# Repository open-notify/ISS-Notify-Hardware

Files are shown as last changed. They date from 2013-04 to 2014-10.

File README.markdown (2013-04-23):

# ISS Notify Hardware

ISS Notify is an open hardware project to make a desktop notification lamp
specifically for overhead passes for the International Space Station for a
users location.

ISS Notify is a simple 2 layer board with an AVR microcontroller with USB
and a set of RGB LEDs LED driver/shift registers. It also has a 
real time clock and a LiPo batter charging circuit.

This repo has all of the design files needed for producing the hardware.

Designed in Eagle version 6.3.

Licensed under the TAPR Open Hardware License (www.tapr.org/OHL). See 
LICENSE.txt for full license information.

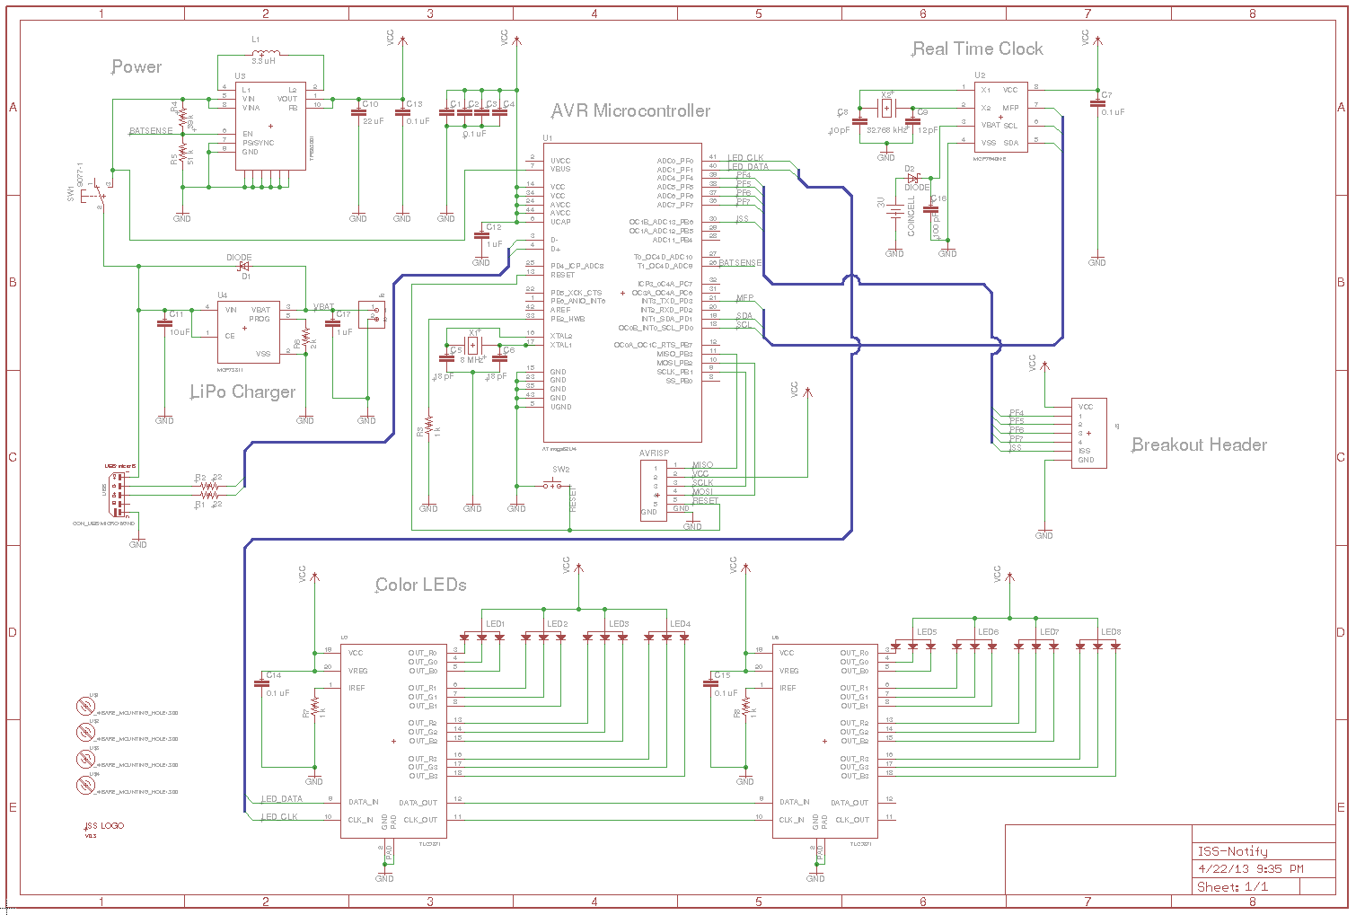
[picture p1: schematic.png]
preview of schematic


 - Download pdf [schematic.pdf](https://github.com/open-notify/ISS-Notify-Hardware/raw/master/schematic.pdf)

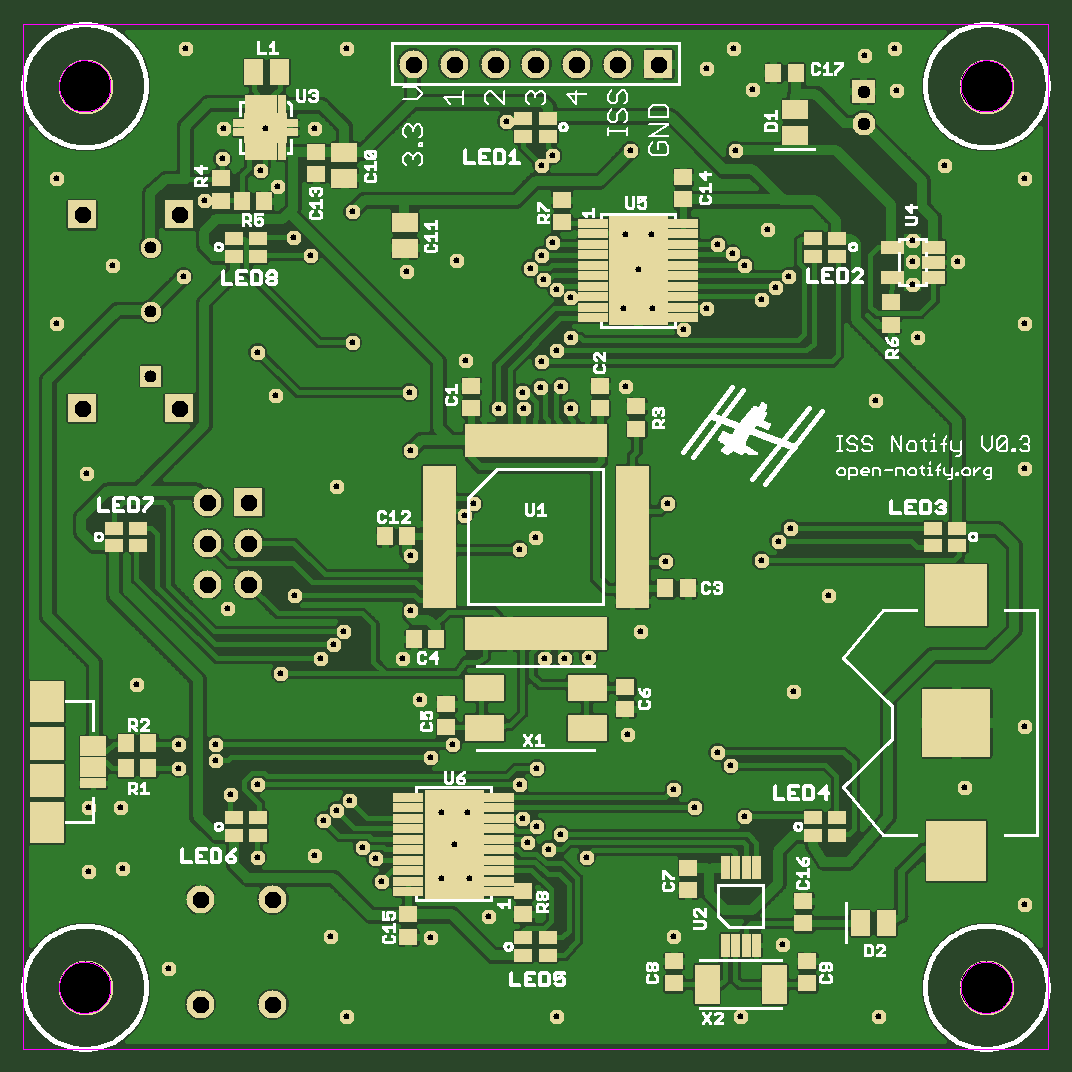
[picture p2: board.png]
preview of board


 - Download pdf [board.pdf](https://github.com/open-notify/ISS-Notify-Hardware/raw/master/board.pdf)

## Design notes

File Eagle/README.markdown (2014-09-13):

# Eagle Files

 - `eagle.epf`: Eagle project
 - `ISS-Notify.lbr`: Eagle parts library
 - `ISS-Notify.sch`: Main board schematic
 - `ISS-Notify.brd`: Main board boardfile
 - `ISS-Notify_Test-Harness.sch`: Test Harness schematic
 - `ISS-Notify_Test-Harness.brd`: Test Harness board

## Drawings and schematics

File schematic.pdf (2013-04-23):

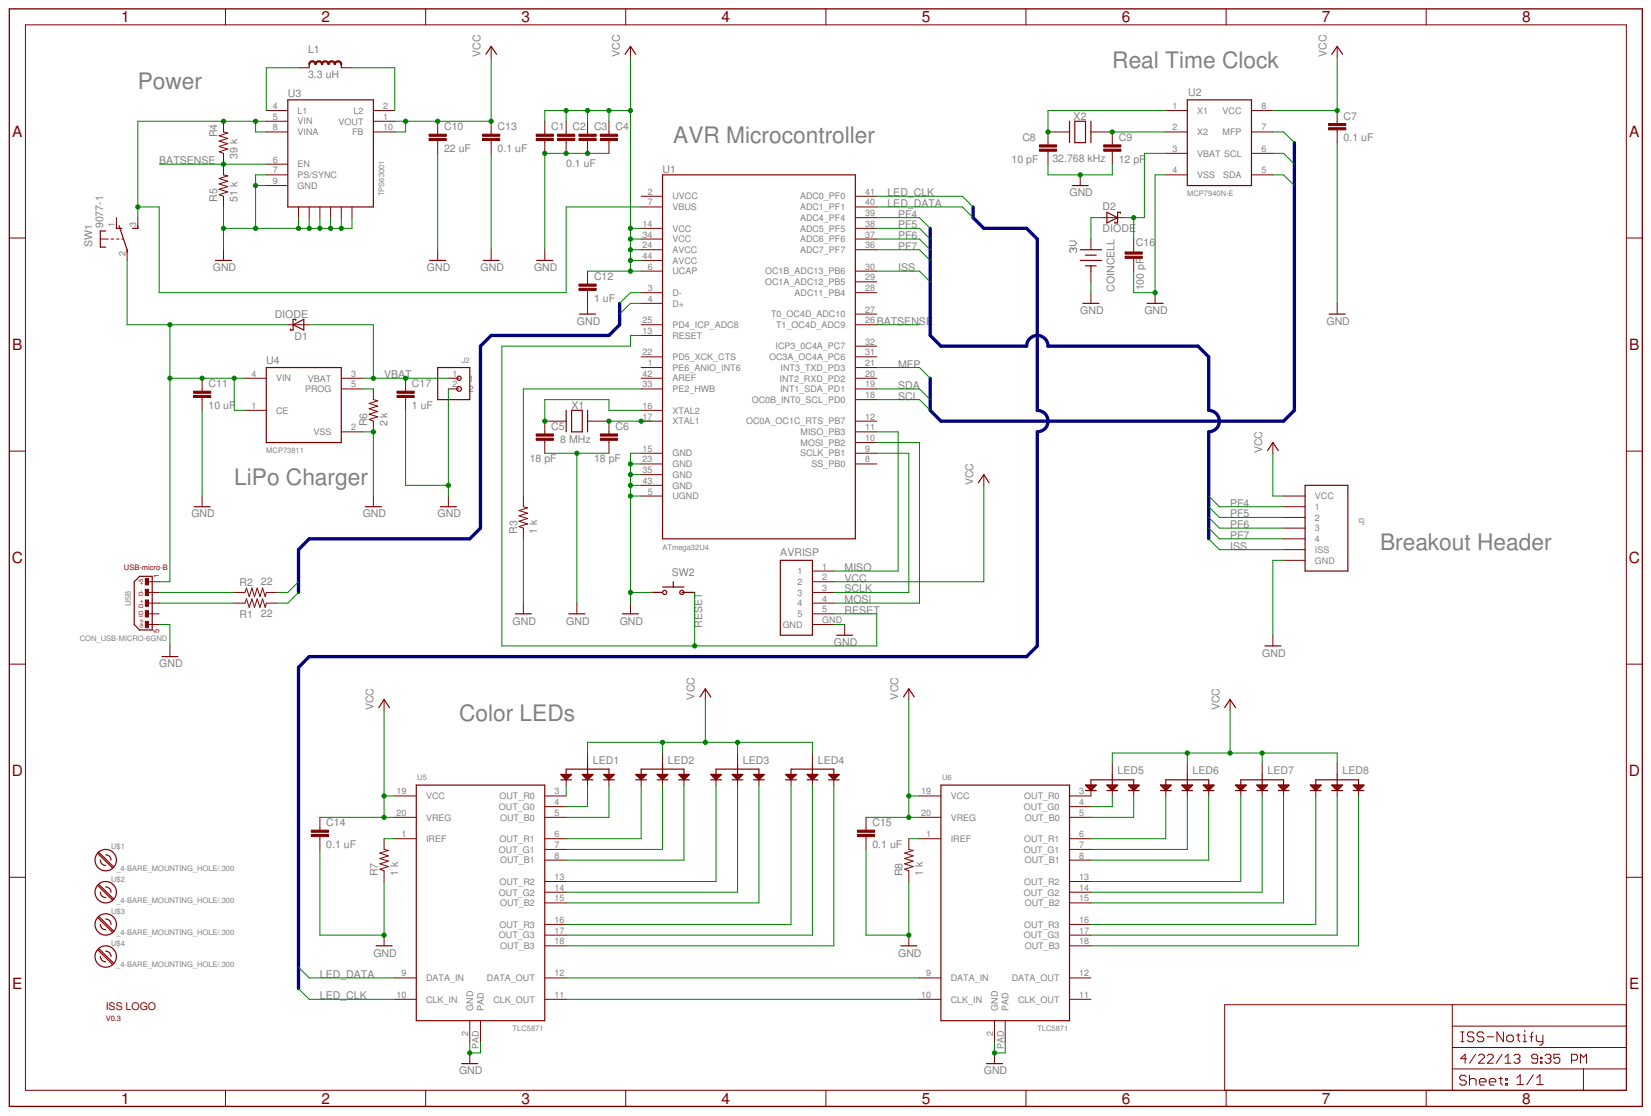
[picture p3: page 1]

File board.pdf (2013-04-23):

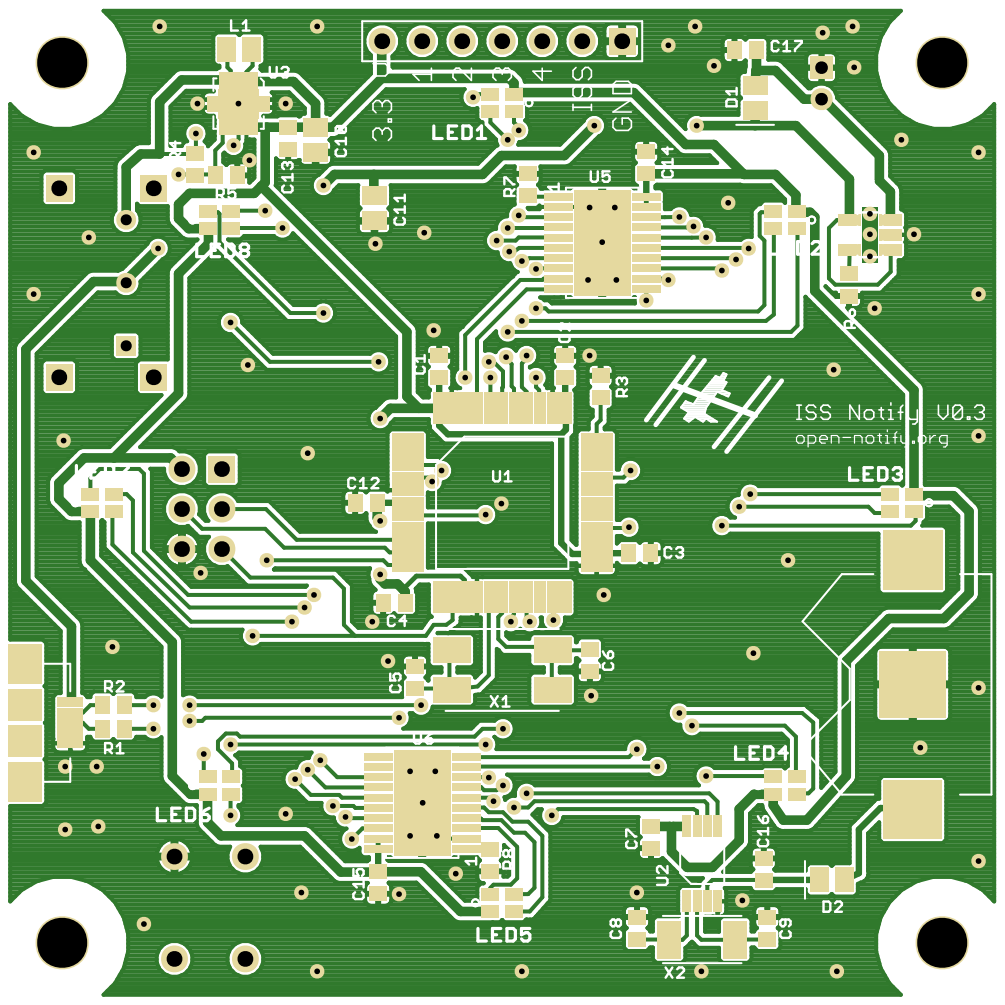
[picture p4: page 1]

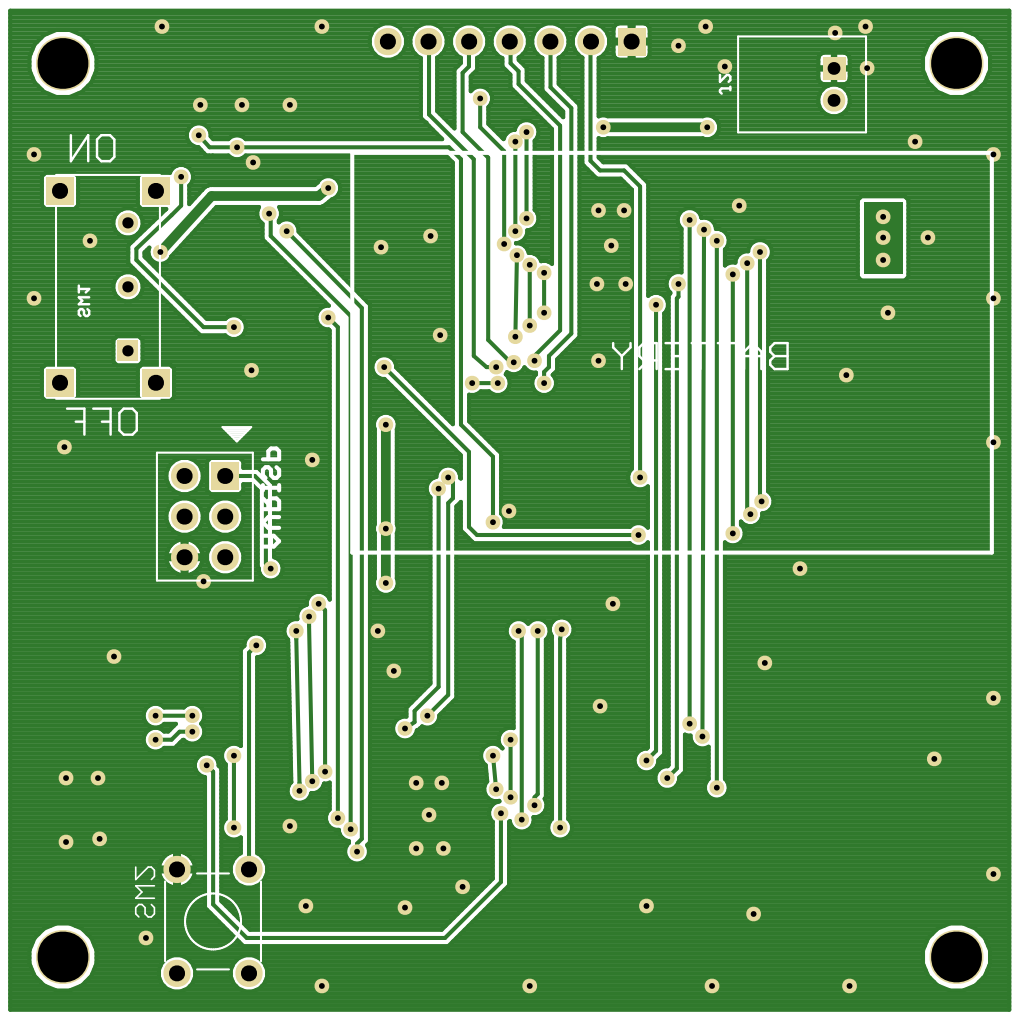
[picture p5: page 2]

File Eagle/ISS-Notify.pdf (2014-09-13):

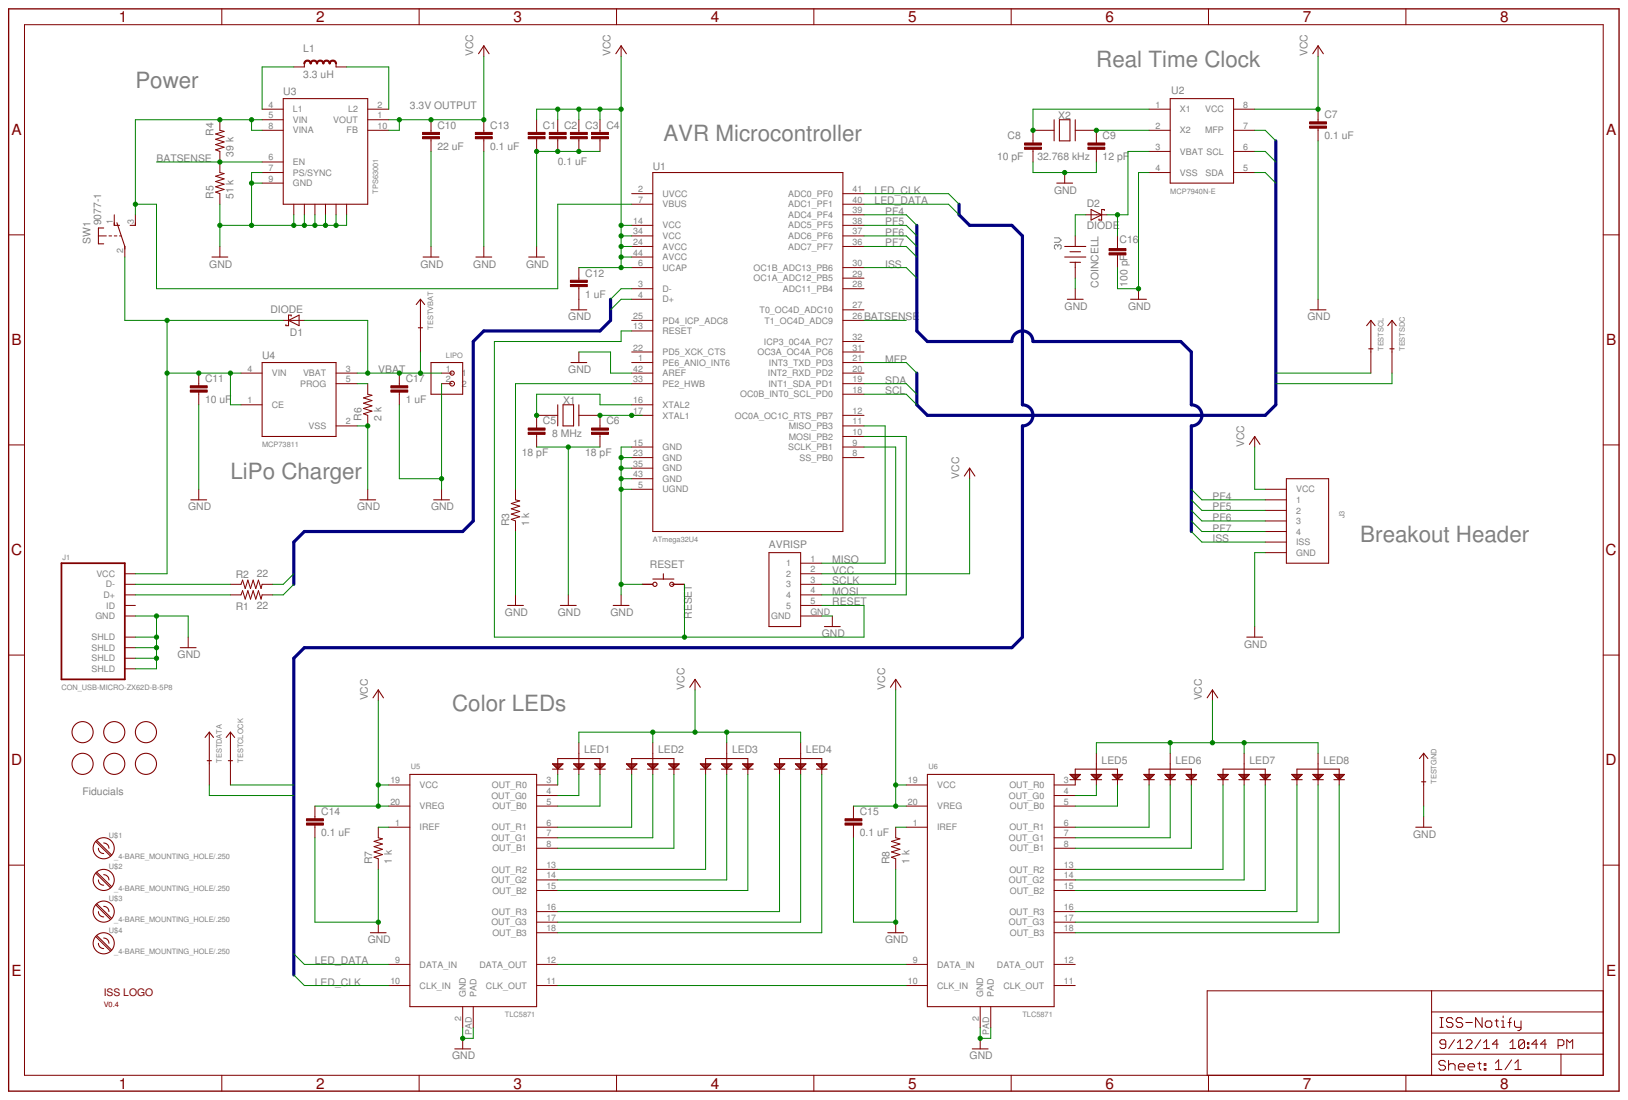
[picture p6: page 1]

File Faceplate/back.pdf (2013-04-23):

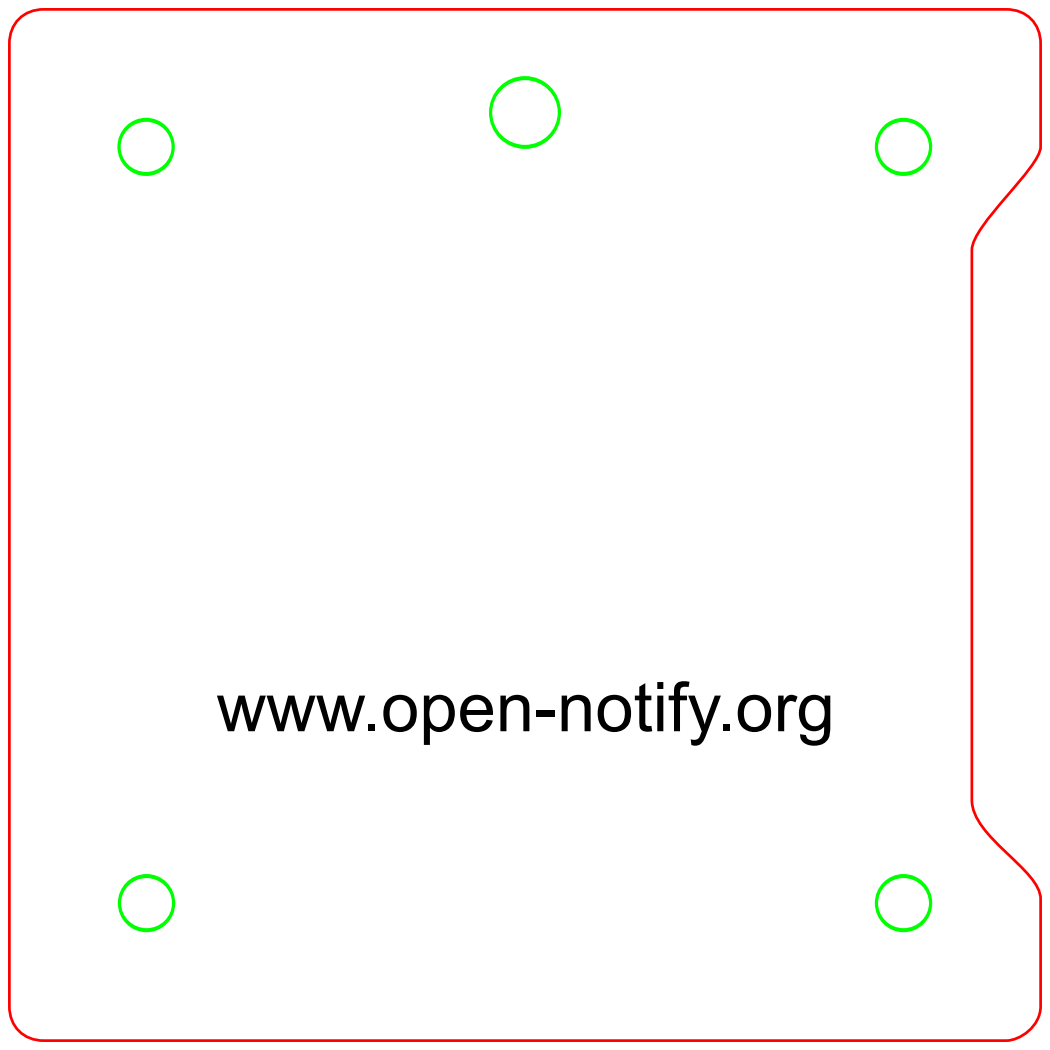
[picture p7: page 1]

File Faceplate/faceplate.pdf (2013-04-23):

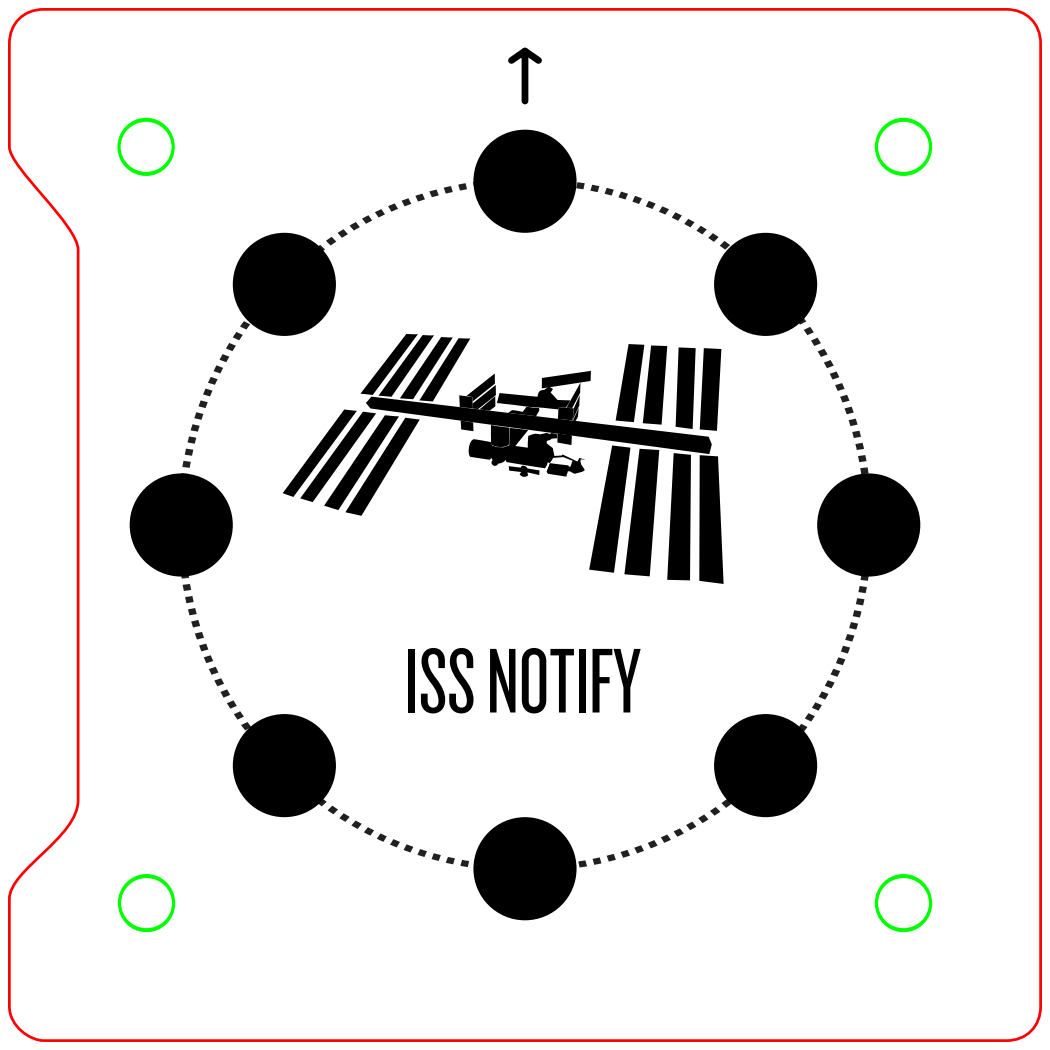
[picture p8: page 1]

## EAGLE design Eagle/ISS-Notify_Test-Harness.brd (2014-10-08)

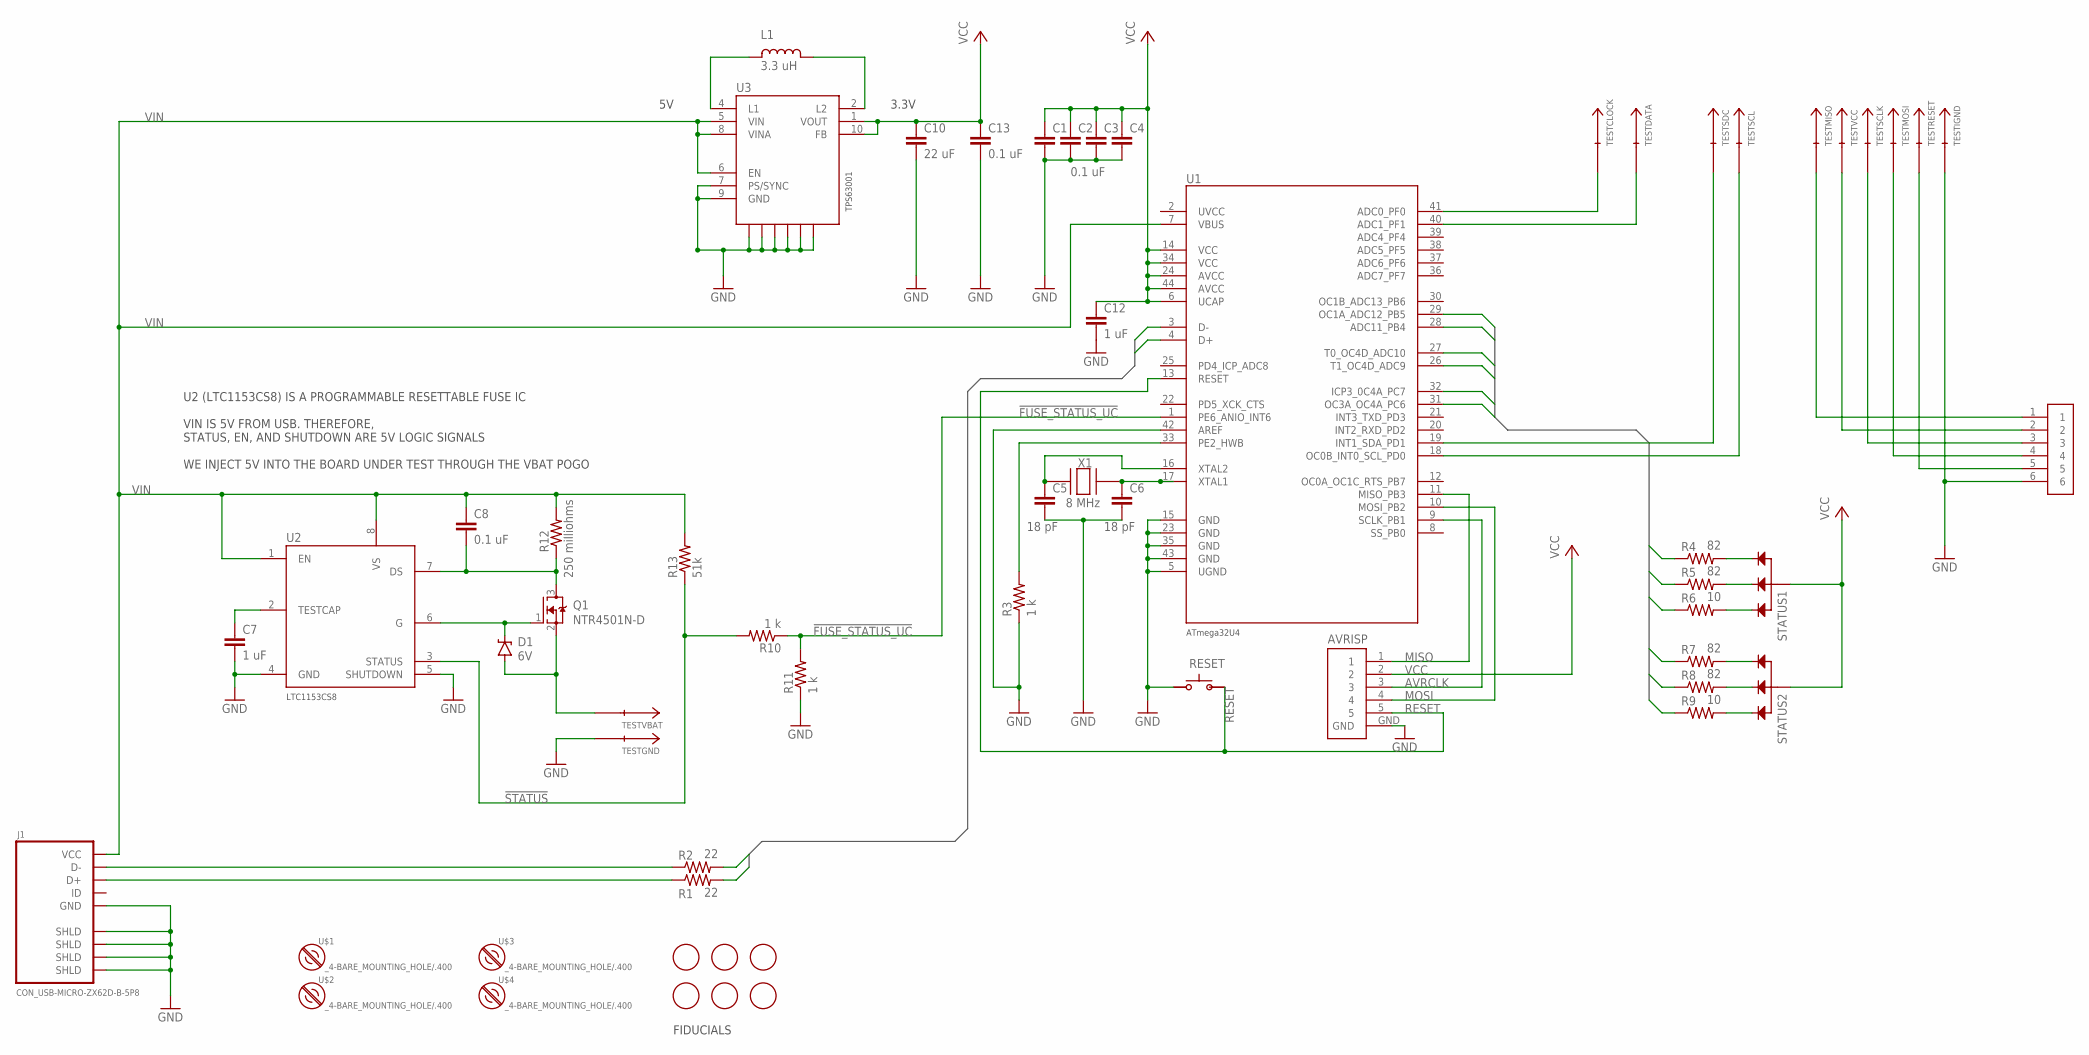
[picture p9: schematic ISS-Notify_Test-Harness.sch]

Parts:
AVRISP: AVRISP
C1, C2, C3, C4, C8, C13: 0.1 uF; 0603-C-NOSILK
C5, C6: 18 pF; 0603-C-NOSILK
C7, C12: 1 uF; 0603-C-NOSILK
C10: 22 uF; 0805-C-NOSILK
D1: 6V; SOD-323
F1, F2, F3, F4, F5, F6: FIDUCIAL; FIDUCIAL_1MM
J1: CON_USB-MICRO-ZX62D-B-5P8; USBMICROSMT-HIROSE
JPROGRAMER: 6HEADER; 6HEAD
L1: 3.3 uH; 0805-C-NOSILK
Q1: NTR4501N-D; SOT-23
R1, R2: 22; 0603-C-NOSILK
R3, R10, R11: 1 k; 0603-C-NOSILK
R4, R5, R7, R8: 82; 0603-C-NOSILK
R6, R9: 10; 0603-C-NOSILK
R12: 250 milliohms; 0603-C-NOSILK
R13: 51k; 0603-C-NOSILK
RESET: SWITCH
STATUS1, STATUS2: RGBLED; SMDRGBLED
TESTCLOCK: POGOPIN
TESTDATA: POGOPIN
TESTGND: POGOPIN
TESTIGND: POGOPIN
TESTMISO: POGOPIN
TESTMOSI: POGOPIN
TESTRESET: POGOPIN
TESTSCL: POGOPIN
TESTSCLK: POGOPIN
TESTSDC: POGOPIN
TESTVBAT: POGOPIN
TESTVCC: POGOPIN
U1: ATMEGA32U4; TQFP-44
U2: LTC1153CS8; SO-8
U3: TPS63001; QFN10
U$1, U$2, U$3, U$4: _4-BARE_MOUNTING_HOLE/.400; _4/.400-BARE+STD_TOOL_CLEARANCE
X1: 8 MHz; CX5Z

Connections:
!FUSE_STATUS_UC: R10.1, R11.2, U1.1 (PE6_ANIO_INT6)
!STATUS: R10.2, R13.1, U2.3 (STATUS)
AVRCLK: AVRISP.3, U1.9 (SCLK_PB1)
D+: R1.2, U1.4 (D+)
D-: R2.2, U1.3 (D-)
GND: AVRISP.GND, C1.2, C2.2, C3.2, C4.2, C5.2, C6.2, C7.2, C10.2, C12.2, C13.2, J1.P5 (GND), J1.P$1 (SHLD), J1.P$2 (SHLD), J1.P$3 (SHLD), J1.P$4 (SHLD), JPROGRAMER.6, R3.1, R11.1, RESET.3 (2), TESTGND.1, TESTIGND.1, U1.5 (UGND), U1.15 (GND), U1.23 (GND), U1.35 (GND), U1.42 (AREF), U1.43 (GND), U2.4 (GND), U2.5 (SHUTDOWN), U3.3 (PGND), U3.7 (PS/SYNC), U3.9 (GND), U3.PAD (GNDPAD), U3.PGND1, U3.PGND2, U3.PGND3, U3.PGND4
LED1_B: R6.1, U1.29 (OC1A_ADC12_PB5)
LED1_G: R5.1, U1.32 (ICP3_0C4A_PC7)
LED1_R: R4.1, U1.31 (OC3A_OC4A_PC6)
LED2_B: R9.1, U1.26 (T1_OC4D_ADC9)
LED2_G: R8.1, U1.28 (ADC11_PB4)
LED2_R: R7.1, U1.27 (T0_OC4D_ADC10)
LED_CLK: TESTCLOCK.1, U1.41 (ADC0_PF0)
LED_DATA: TESTDATA.1, U1.40 (ADC1_PF1)
MISO: AVRISP.1, U1.11 (MISO_PB3)
MOSI: AVRISP.4, U1.10 (MOSI_PB2)
unnamed: L1.1 (A), U3.4 (L1)
unnamed: L1.2 (C), U3.2 (L2)
unnamed: R4.2, STATUS1.RED (R)
unnamed: J1.P3 (D+), R1.1
unnamed: J1.P2 (D-), R2.1
unnamed: C5.1, U1.16 (XTAL2), X1.1
unnamed: R5.2, STATUS1.GREEN (G)
unnamed: R6.2, STATUS1.BLUE (B)
unnamed: R7.2, STATUS2.RED (R)
unnamed: C6.1, U1.17 (XTAL1), X1.3 (2)
unnamed: R8.2, STATUS2.GREEN (G)
unnamed: R9.2, STATUS2.BLUE (B)
unnamed: C7.1, U2.2 (TESTCAP)
unnamed: C8.2, Q1.3 (D), R12.1, U2.7 (DS)
unnamed: D1.C, Q1.1 (G), U2.6 (G)
unnamed: D1.A, Q1.2 (S), TESTVBAT.1
unnamed: R3.2, U1.33 (PE2_HWB)
RESET: AVRISP.5, RESET.1, U1.13 (RESET)
SCL: TESTSCL.1, U1.18 (OC0B_INT0_SCL_PD0)
SDA: TESTSDC.1, U1.19 (INT1_SDA_PD1)
TESTMISO: JPROGRAMER.1, TESTMISO.1
TESTMOSI: JPROGRAMER.4, TESTMOSI.1
TESTRESET: JPROGRAMER.5, TESTRESET.1
TESTSCLK: JPROGRAMER.3, TESTSCLK.1
TESTVCC: JPROGRAMER.2, TESTVCC.1
UVCC: U1.2 (UVCC)
VCC: AVRISP.2, C1.1, C2.1, C3.1, C4.1, C10.1, C12.1, C13.1, STATUS1.ANODE, STATUS2.ANODE, U1.6 (UCAP), U1.14 (VCC), U1.24 (AVCC), U1.34 (VCC), U1.44 (AVCC), U3.1 (VOUT), U3.10 (FB)
VIN: C8.1, J1.P1 (VCC), R12.2, R13.2, U1.7 (VBUS), U2.1 (EN), U2.8 (VS), U3.5 (VIN), U3.6 (EN), U3.8 (VINA)

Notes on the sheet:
3.3V
U2 (LTC1153CS8) IS A PROGRAMMABLE RESETTABLE FUSE IC VIN IS 5V FROM USB. THEREFORE, STATUS, EN, AND SHUTDOWN ARE 5V LOGIC SIGNALS WE INJECT 5V INTO THE BOARD UNDER TEST THROUGH THE VBAT POGO
FIDUCIALS

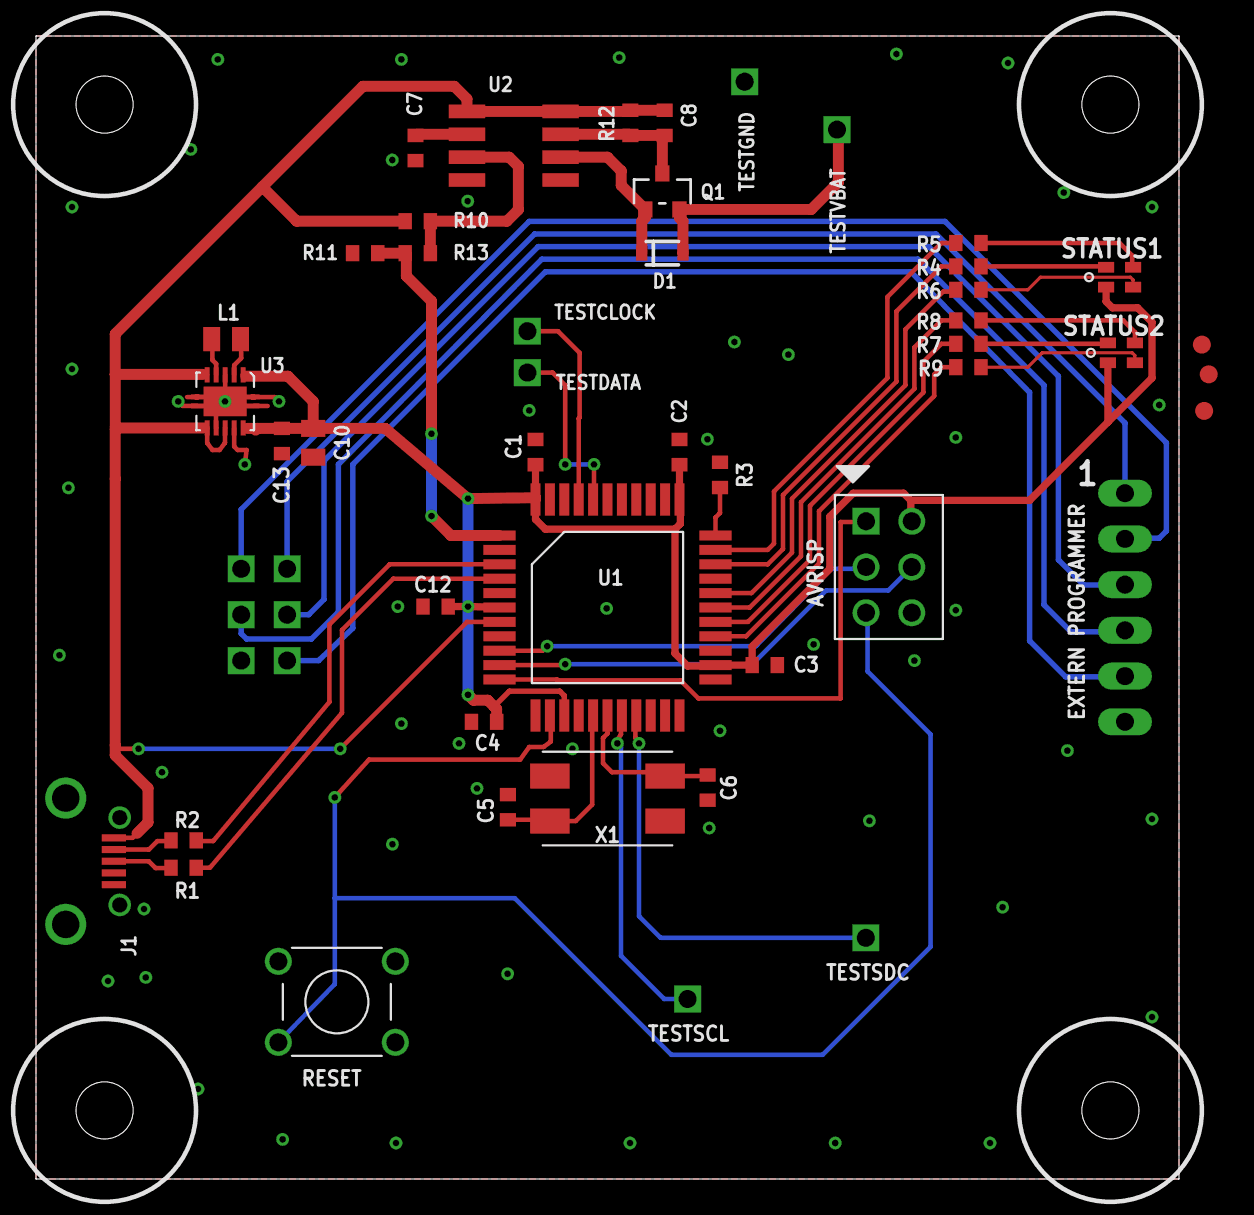
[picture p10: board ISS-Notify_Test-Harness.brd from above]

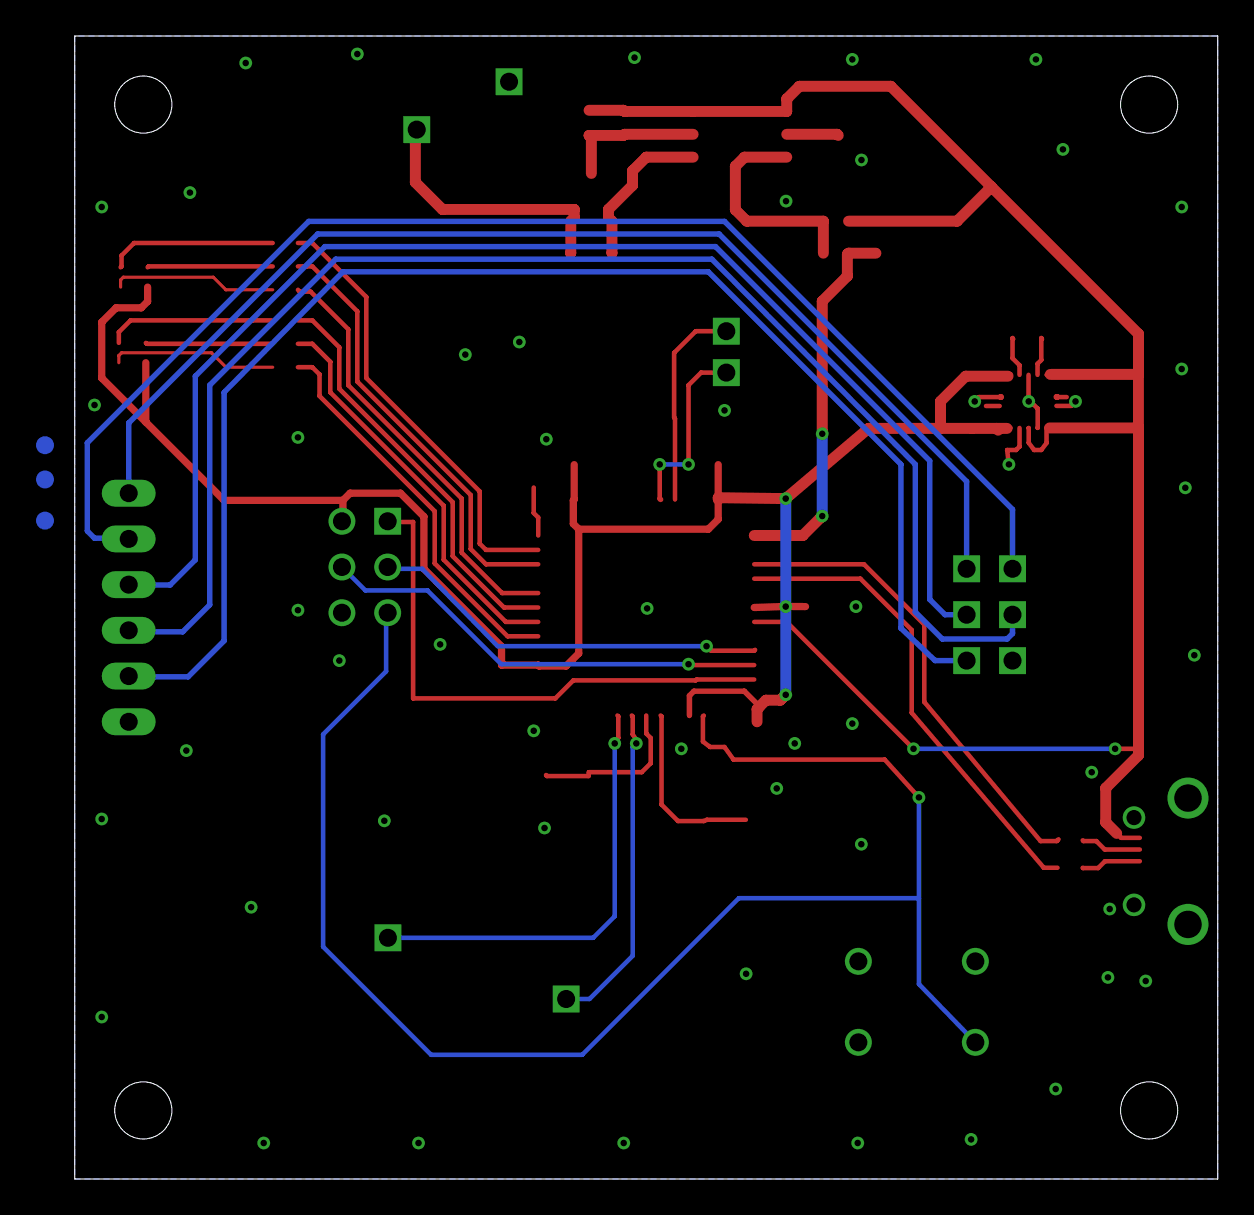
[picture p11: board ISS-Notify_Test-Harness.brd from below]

Board: 2 copper layers, 63.5 x 63.5 mm, 59 parts (3 on the bottom side), 43 nets.

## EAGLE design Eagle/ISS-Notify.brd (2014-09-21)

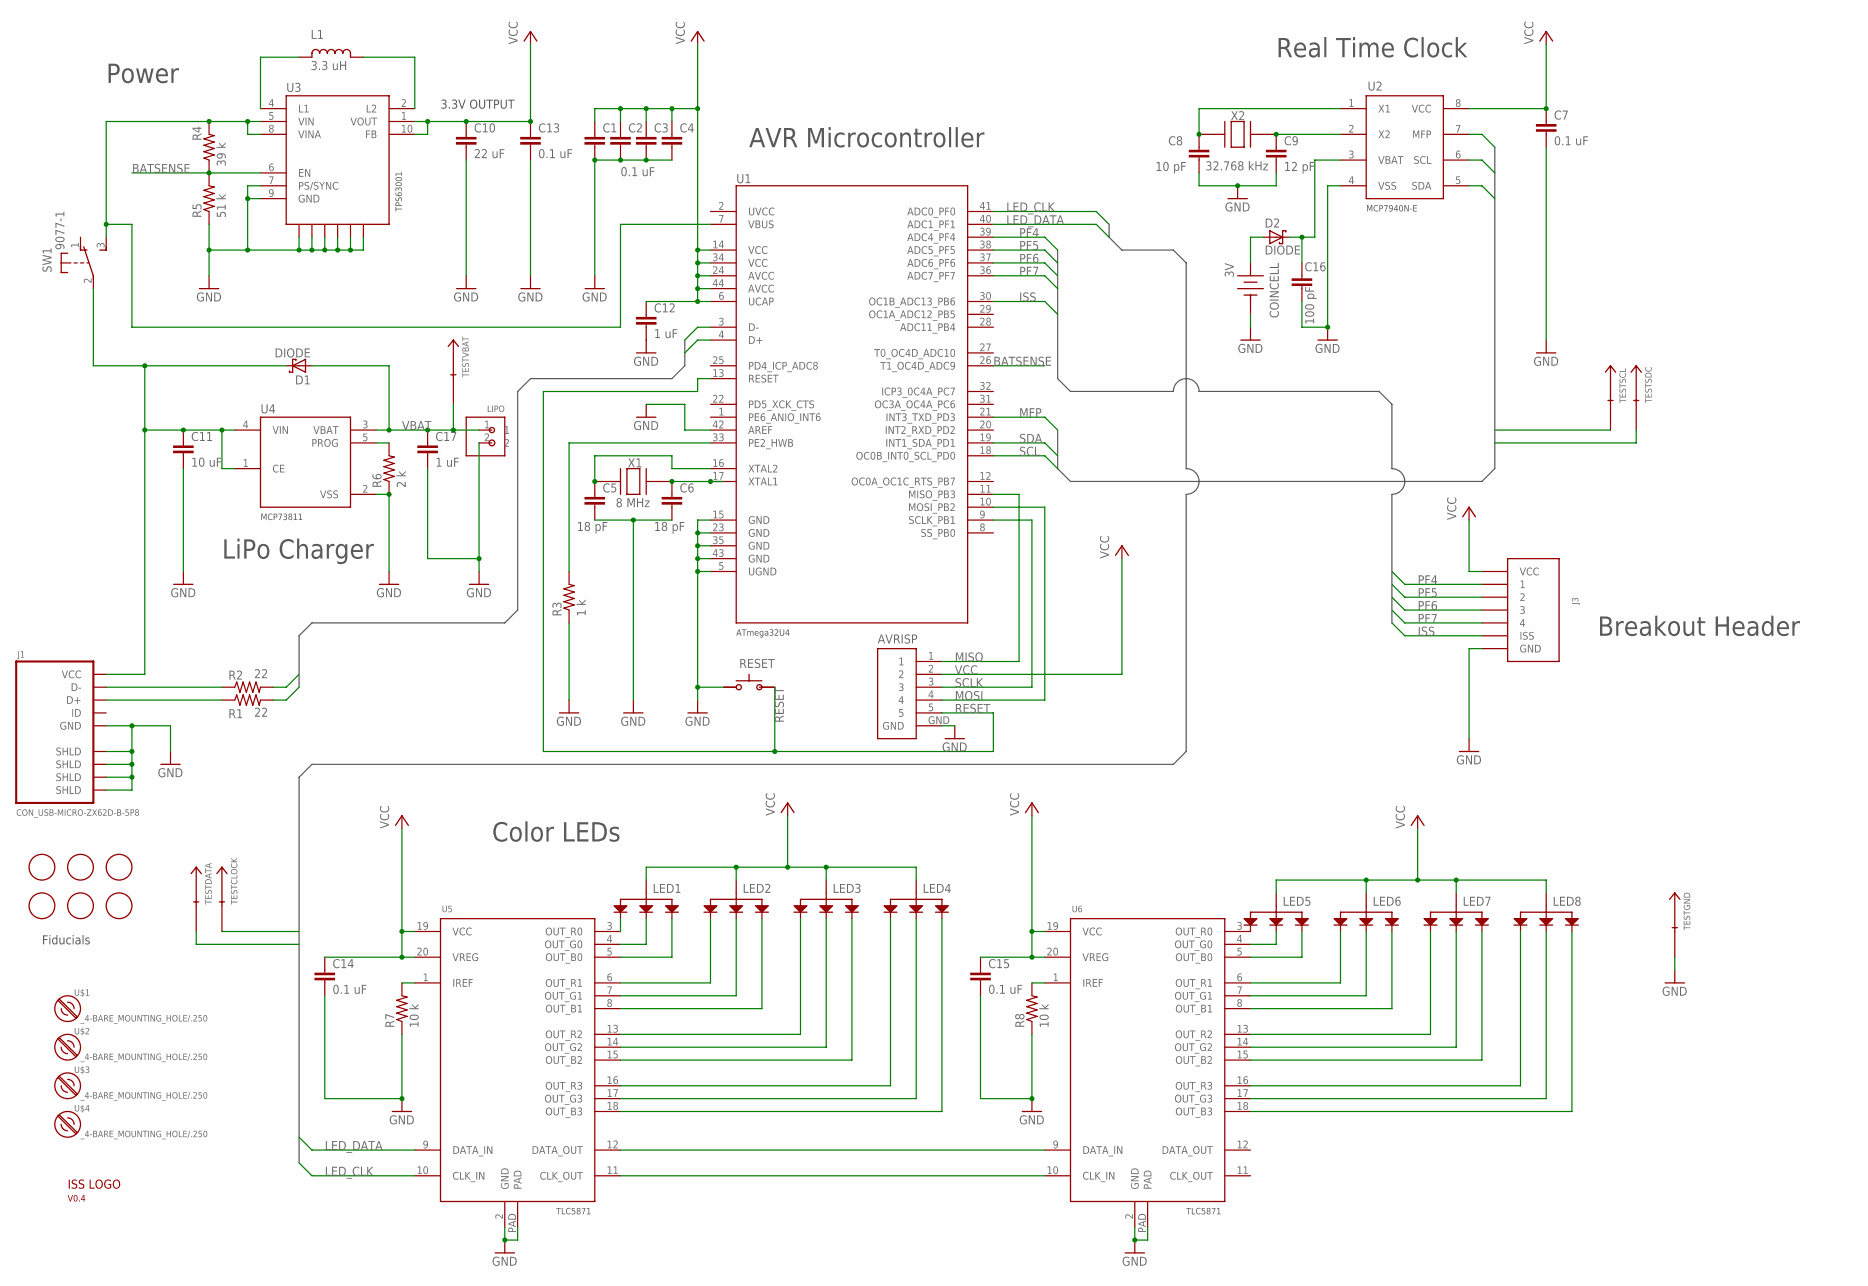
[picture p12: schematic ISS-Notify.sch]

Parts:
AVRISP: AVRISP
C1, C2, C3, C4, C7, C13, C14, C15: 0.1 uF; 0603-C-NOSILK
C5, C6: 18 pF; 0603-C-NOSILK
C8: 10 pF; 0603-C-NOSILK
C9: 12 pF; 0603-C-NOSILK
C10: 22 uF; 0805-C-NOSILK
C11: 10 uF; 0805-C-NOSILK
C12, C17: 1 uF; 0603-C-NOSILK
C16: 100 pF; 0603-C-NOSILK
COINCELL: 3V; COINCELL
D1, D2: DIODE; 0805-DIODE
J1: CON_USB-MICRO-ZX62D-B-5P8; USBMICROSMT-HIROSE
J3: PROTOSPACE2
L1: 3.3 uH; 0805-C-NOSILK
LED1, LED2, LED3, LED4, LED5, LED6, LED7, LED8: RGBLED; SMDRGBLED
LIPO: JST2; JSTHEAD
R1, R2: 22; 0603-C-NOSILK
R3: 1 k; 0603-C-NOSILK
R4: 39 k; 0603-C-NOSILK
R5: 51 k; 0603-C-NOSILK
R6: 2 k; 0603-C-NOSILK
R7, R8: 10 k; 0603-C-NOSILK
RESET: SWITCH
SW1: 9077-1; ESWITCH
TESTCLOCK: TESTPIN
TESTDATA: TESTPIN
TESTGND: TESTPIN
TESTSCL: TESTPIN
TESTSDC: TESTPIN
TESTVBAT: TESTPIN
U1: ATMEGA32U4; TQFP-44
U2: MCP7940N
U3: TPS63001; QFN10
U4: MCP73811; SOT23-5L
U5, U6: TLC5971; R-PDSO-G20
U$1, U$2, U$3, U$4: _4-BARE_MOUNTING_HOLE/.250; _4/.250-BARE+STD_WASHER
U$5: V0.4; LOGO
U$6, U$7, U$8, U$9, U$10, U$11: FIDUCIAL; FIDUCIAL_1MM
X1: 8 MHz; CX5Z
X2: 32.768 kHz; ABS10

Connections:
BATSENSE: R4.1, R5.2, U1.26 (T1_OC4D_ADC9), U3.6 (EN)
D+: R1.2, U1.4 (D+)
D-: R2.2, U1.3 (D-)
GND: AVRISP.GND, C1.2, C2.2, C3.2, C4.2, C5.2, C6.2, C7.2, C8.2, C9.2, C10.2, C11.2, C12.2, C13.2, C14.2, C15.2, C16.2, C17.2, COINCELL.GND, J1.P5 (GND), J1.P$1 (SHLD), J1.P$2 (SHLD), J1.P$3 (SHLD), J1.P$4 (SHLD), J3.GND, LIPO.2, R3.1, R5.1, R6.1, R7.1, R8.1, RESET.3 (2), TESTGND.P$1, U1.5 (UGND), U1.15 (GND), U1.23 (GND), U1.35 (GND), U1.42 (AREF), U1.43 (GND), U2.4 (VSS), U3.3 (PGND), U3.7 (PS/SYNC), U3.9 (GND), U3.PAD (GNDPAD), U3.PGND1, U3.PGND2, U3.PGND3, U3.PGND4, U4.2 (VSS), U5.2 (GND), U5.PAD, U6.2 (GND), U6.PAD
ISS: J3.ISS, U1.30 (OC1B_ADC13_PB6)
LED_CLK: TESTCLOCK.P$1, U1.41 (ADC0_PF0), U5.10 (CLK_IN)
LED_DATA: TESTDATA.P$1, U1.40 (ADC1_PF1), U5.9 (DATA_IN)
MFP: U1.21 (INT3_TXD_PD3), U2.7 (MFP)
MISO: AVRISP.1, U1.11 (MISO_PB3)
MOSI: AVRISP.4, U1.10 (MOSI_PB2)
unnamed: L1.1 (A), U3.4 (L1)
unnamed: L1.2 (C), U3.2 (L2)
unnamed: J1.P3 (D+), R1.1
unnamed: J1.P2 (D-), R2.1
unnamed: C5.1, U1.16 (XTAL2), X1.1
unnamed: C9.1, U2.2 (X2), X2.@1 (2)
unnamed: C8.1, U2.1 (X1), X2.1
unnamed: C6.1, U1.17 (XTAL1), X1.3 (2)
unnamed: COINCELL.POS1 (VBAT), D2.A
unnamed: R6.2, U4.5 (PROG)
unnamed: U5.11 (CLK_OUT), U6.10 (CLK_IN)
unnamed: U5.12 (DATA_OUT), U6.9 (DATA_IN)
unnamed: C16.1, D2.C, U2.3 (VBAT)
unnamed: LED2.BLUE (B), U5.8 (OUT_B1)
unnamed: R7.2, U5.1 (IREF)
unnamed: R8.2, U6.1 (IREF)
unnamed: LED3.RED (R), U5.13 (OUT_R2)
unnamed: LED3.GREEN (G), U5.14 (OUT_G2)
unnamed: LED3.BLUE (B), U5.15 (OUT_B2)
unnamed: LED1.RED (R), U5.3 (OUT_R0)
unnamed: LED1.GREEN (G), U5.4 (OUT_G0)
unnamed: LED1.BLUE (B), U5.5 (OUT_B0)
unnamed: LED2.RED (R), U5.6 (OUT_R1)
unnamed: LED2.GREEN (G), U5.7 (OUT_G1)
unnamed: LED4.RED (R), U5.16 (OUT_R3)
unnamed: LED4.GREEN (G), U5.17 (OUT_G3)
unnamed: LED4.BLUE (B), U5.18 (OUT_B3)
unnamed: LED7.RED (R), U6.13 (OUT_R2)
unnamed: LED5.RED (R), U6.3 (OUT_R0)
unnamed: LED5.GREEN (G), U6.4 (OUT_G0)
unnamed: LED5.BLUE (B), U6.5 (OUT_B0)
unnamed: LED6.RED (R), U6.6 (OUT_R1)
unnamed: LED6.GREEN (G), U6.7 (OUT_G1)
unnamed: LED6.BLUE (B), U6.8 (OUT_B1)
unnamed: LED7.GREEN (G), U6.14 (OUT_G2)
unnamed: LED7.BLUE (B), U6.15 (OUT_B2)
unnamed: LED8.RED (R), U6.16 (OUT_R3)
unnamed: LED8.GREEN (G), U6.17 (OUT_G3)
unnamed: LED8.BLUE (B), U6.18 (OUT_B3)
unnamed: R3.2, U1.33 (PE2_HWB)
PF4: J3.1, U1.39 (ADC4_PF4)
PF5: J3.2, U1.38 (ADC5_PF5)
PF6: J3.3, U1.37 (ADC6_PF6)
PF7: J3.4, U1.36 (ADC7_PF7)
RESET: AVRISP.5, RESET.1, U1.13 (RESET)
SCL: TESTSCL.P$1, U1.18 (OC0B_INT0_SCL_PD0), U2.6 (SCL)
SCLK: AVRISP.3, U1.9 (SCLK_PB1)
SDA: TESTSDC.P$1, U1.19 (INT1_SDA_PD1), U2.5 (SDA)
UVCC: U1.2 (UVCC)
VBAT: C17.1, D1.A, LIPO.1, TESTVBAT.P$1, U4.3 (VBAT)
VCC: AVRISP.2, C1.1, C2.1, C3.1, C4.1, C7.1, C10.1, C12.1, C13.1, C14.1, C15.1, J3.VCC, LED1.ANODE, LED2.ANODE, LED3.ANODE, LED4.ANODE, LED5.ANODE, LED6.ANODE, LED7.ANODE, LED8.ANODE, U1.6 (UCAP), U1.14 (VCC), U1.24 (AVCC), U1.34 (VCC), U1.44 (AVCC), U2.8 (VCC), U3.1 (VOUT), U3.10 (FB), U5.19 (VCC), U5.20 (VREG), U6.19 (VCC), U6.20 (VREG)
VIN: R4.2, SW1.3 (S), U1.7 (VBUS), U3.5 (VIN), U3.8 (VINA)
VUSB: C11.1, D1.C, J1.P1 (VCC), SW1.2, U4.1 (CE), U4.4 (VIN)

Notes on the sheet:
LiPo Charger
Power
AVR Microcontroller
Real Time Clock
Color LEDs
Breakout Header
Fiducials
3.3V OUTPUT

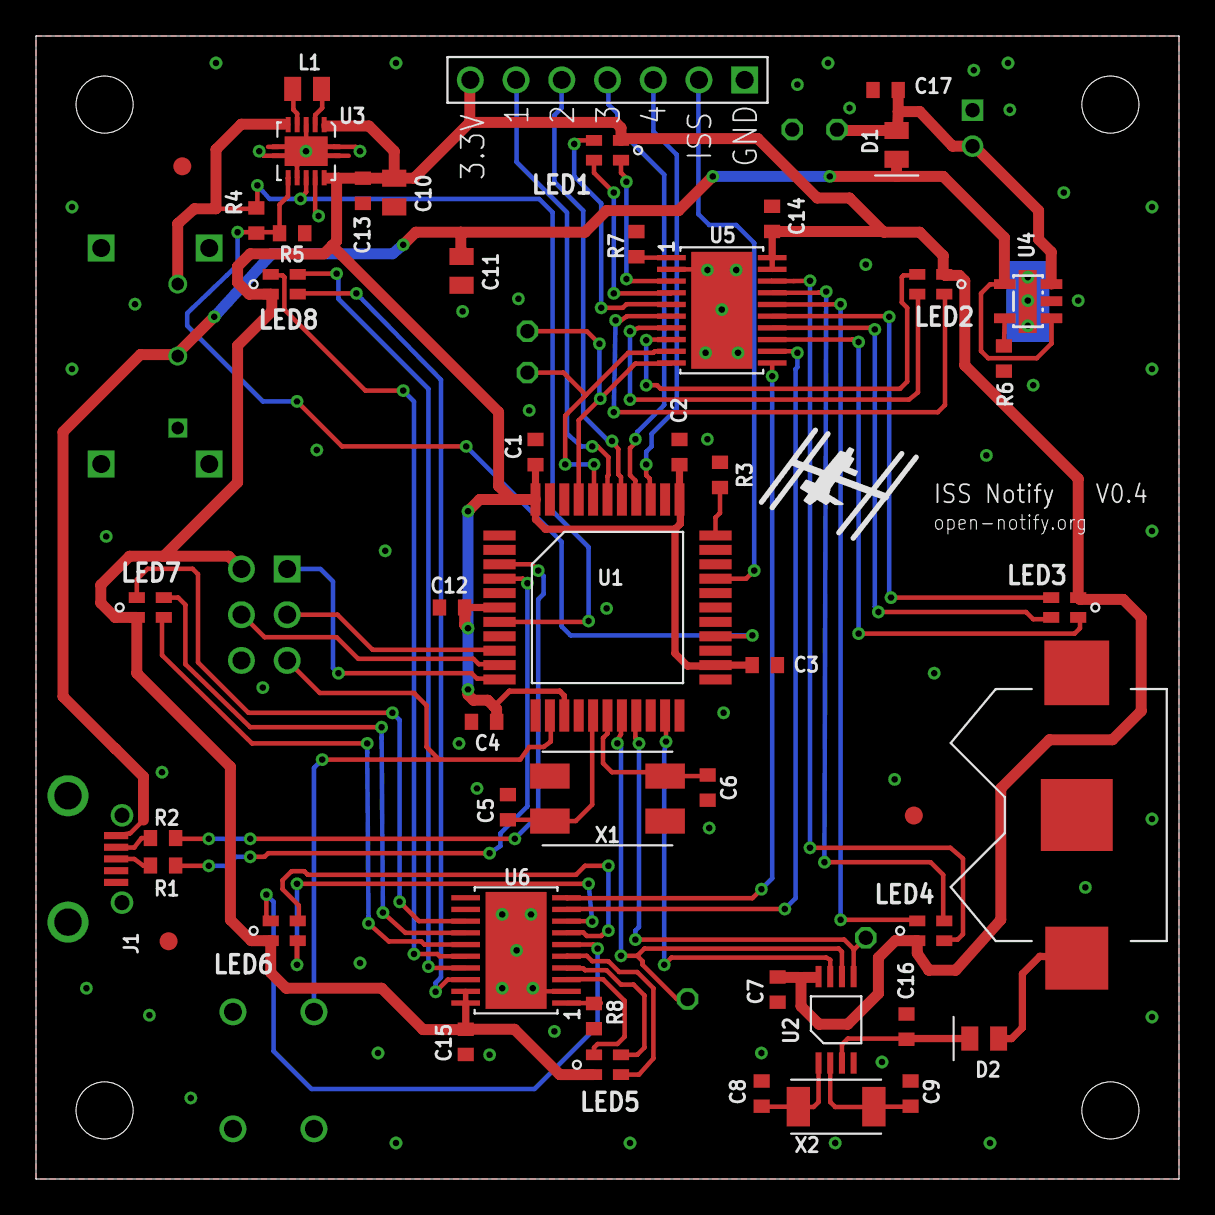
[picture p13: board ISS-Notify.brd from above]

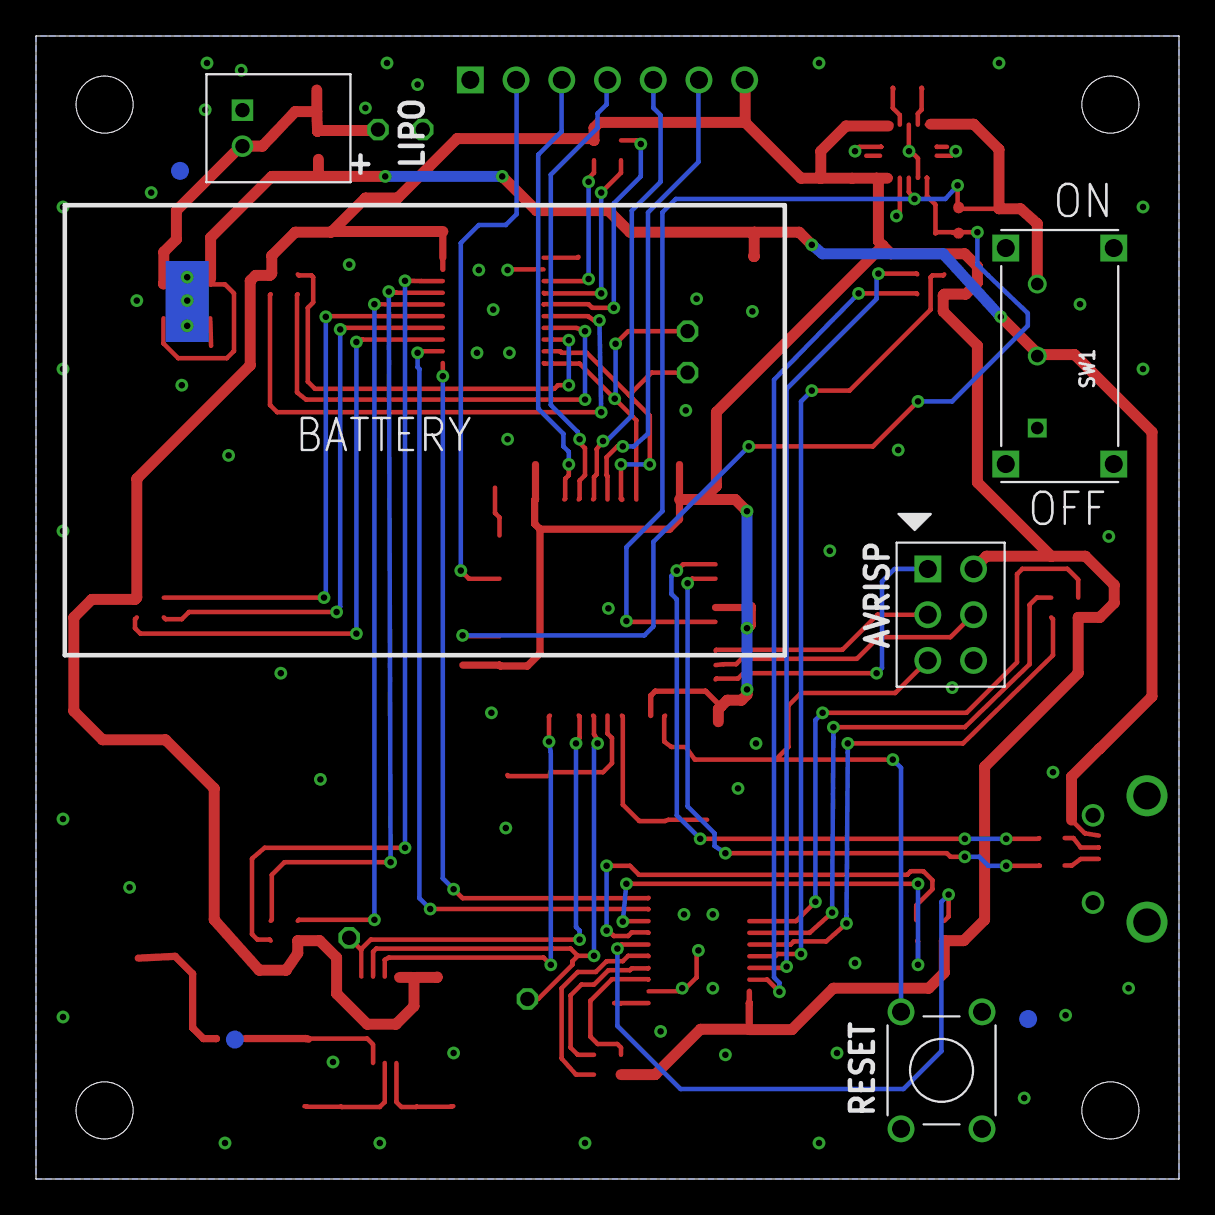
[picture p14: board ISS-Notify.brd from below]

Board: 2 copper layers, 63.5 x 63.5 mm, 68 parts (7 on the bottom side), 62 nets.

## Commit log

2011-08-11 first commit, work so far
    [Open_Notify.sch]
2011-10-17 Added LED circle and LED driver
    [Open_Notify.sch]
2011-10-27 moved things around for clarity
    [Open_Notify.sch]
2011-10-27 Added AVR_ISP
    [Open_Notify.sch]
2011-12-08 corrections and connections and decoupling capaciters
    [Open_Notify.sch]
2011-12-08 protoboard space
    [Open_Notify.sch]
2011-12-09 8 MHz crystal for ATMEGA
    [Open_Notify.sch]
2011-12-31 rework with buses and added LiPo support
    [Open_Notify.sch]
2011-12-31 Eagle folder and datasheets
    [Open_Notify.sch]
2011-12-31 busses everywhere
    [Open_Notify.sch]
2011-12-31 Added battery charger into uc
    [Open_Notify.sch]
2012-01-01 smaller frame
    [Open_Notify.sch]
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2012-01-02 voltage dividers
    [Open_Notify.sch]
2012-01-04 Mostly large cosmetic changes to the schematic and careful looking for bugs. Removed SOUT short to ground, removed unecessary diode in Vbus path, added issue list, fixed battery measurement circuit, 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
    [Open_Notify.sch]
2012-01-04 Ran ERC and fixed important warnings and approved stupid ones. Fixes: invoked uninvoked pins on USB connector, STAT1 was connected to uC twice, GBLANK was misnamed in nets.
    [Open_Notify.sch]
2012-01-07 removed UVCC
    [Open_Notify.sch]
2012-01-07 Part names, fixed some parts, some double checking
    [Open_Notify.sch]
2012-01-08 more parts double checked, fixed RTC package
    [Open_Notify.sch]
2012-01-08 replaced TPS3205 with TPS63001
    [Open_Notify.sch]
2012-01-08 finished picking through the RTC, added pretty BOM
    [Open_Notify.sch]
2012-01-10 furthur nit picking. All but a couple of parts fixed, everything listed in BOM
    [Open_Notify.sch]
2012-01-10 added protospace and pdf of schematic
    [Open_Notify.sch]
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2012-01-16 switch and better C2 cap
    [Open_Notify.sch]
2012-01-17 first board design ratsnest
    [Open_Notify.brd, Open_Notify.sch]
2012-01-17 routing R and G LEDs
    [Open_Notify.brd, Open_Notify.sch]
2012-01-18 LED hookups and RTC layout
    [Open_Notify.brd, Open_Notify.sch]
2012-01-18 updated schematic image and pdf. moved LED drives slightly to the right
    [Open_Notify.brd]
2012-01-20 wireing protospace
    [Open_Notify.brd, Open_Notify.sch]
2012-01-26 groung planes
    [Open_Notify.brd]
2012-02-13 tweaked ground plane
    [Open_Notify.brd]
2012-03-07 Started laying power
    [Open_Notify.brd]
2012-03-23 improved pwr routing
    [Open_Notify.brd, Open_Notify.sch]
2012-03-24 Layout ver 1
    [Open_Notify.brd]
2012-04-01 power pad
    [Open_Notify.brd, Open_Notify.sch]
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2012-04-06 Fixes, fixes, and DRC checkout
    [Open_Notify.brd, Open_Notify.sch]
2012-04-06 Text and logos added to screen layer
    [Open_Notify.brd, Open_Notify.sch]
2012-04-06 replaced charger part with MSOP package
    [Open_Notify.brd, Open_Notify.sch]
2012-04-06 clean design
    [Open_Notify.brd, Open_Notify.sch]
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2012-04-10 Fixes from laying out parts on paper
    [Open_Notify.brd, Open_Notify.sch]
2012-04-12 tweak leads for RTC
    [Open_Notify.brd, Open_Notify.sch]
2012-04-12 Ripped up and re-routed wires from SMT pads to be centered and orthogonal to the side. Moved a few vias for better power routing.
    [Open_Notify.brd]
2012-04-12 Moved a few more vias around for better ground plane.
    [Open_Notify.brd]
2012-04-12 Did a DRC on all layers, fixed a tname over a via, redid ERC, approved a minor warning.
    [Open_Notify.brd, Open_Notify.sch]
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2012-10-09 version 0.2 fixes
    [Open_Notify.brd, Open_Notify.sch]
2012-11-07 more 0.2 fixes
    [Open_Notify.brd, Open_Notify.sch]
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2013-04-16 clean up Eagle directory, upgrade to version 6, start small board
    [ISS-Notify.sch, Open_Notify.brd, Open_Notify.sch]
2013-04-17 power side of schematic
    [ISS-Notify.sch]
2013-04-21 LED and drivers in schematic
    [ISS-Notify.sch]
2013-04-21 LED driver datasheet, Frame and proto header on schematic
    [ISS-Notify.sch]
2013-04-21 removed cam folder, this gets packed to gerbers and can be generated anyway
    [Open_Notify.xln]
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2013-04-22 minor library updates, thermal pad under LiPo charger
    [ISS-Notify.brd, ISS-Notify.sch]
2013-04-22 screen layer cleaned up
    [ISS-Notify.brd]
2013-04-22 tplace for push button
    [ISS-Notify.brd, ISS-Notify.sch]
2013-04-22 edge ground place stipling
    [ISS-Notify.brd]
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2013-04-22 minor trace size fix
    [ISS-Notify.brd]
2013-04-23 Cut gerbers for OSH Park
    [ISS-Notify.brd, ISS-Notify.sch]
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2013-04-23 Update parts after digikey searches
    [ISS-Notify.brd, ISS-Notify.sch]
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2013-09-17 remove wrong traces from XTAL
    [ISS-Notify.brd]
2013-09-17 a couple of astetic trace fixes
    [ISS-Notify.brd]
2013-09-17 names of J2 and reset button so they show up logicall on screenprint
    [ISS-Notify.brd, ISS-Notify.sch]
2013-09-17 updated screen on proto area
    [ISS-Notify.brd, ISS-Notify.sch]
2013-09-17 test pin placement on board
    [ISS-Notify.brd, ISS-Notify.sch]
2013-09-17 incrament board version on screen
    [ISS-Notify.brd, ISS-Notify.sch]
2013-09-17 starting test harness board
    [ISS-Notify_Test-Harness.brd, ISS-Notify_Test-Harness.sch]
2013-09-23 fixed annoying bolt landing, moved a via or two
    [ISS-Notify.brd, ISS-Notify.sch]
2013-09-24 pogo pin landings for test harness
    [ISS-Notify_Test-Harness.brd, ISS-Notify_Test-Harness.sch]
2013-09-24 first pass routing to pogo pins on test harness
    [ISS-Notify_Test-Harness.brd, ISS-Notify_Test-Harness.sch]
2013-10-15 clean up power supply, 6 pin header for programming test board
    [ISS-Notify_Test-Harness.brd, ISS-Notify_Test-Harness.sch]
2013-10-16 external programmer for test board
    [ISS-Notify_Test-Harness.brd, ISS-Notify_Test-Harness.sch]
2013-10-16 2 rgb status LEDs
    [ISS-Notify_Test-Harness.brd, ISS-Notify_Test-Harness.sch]
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2013-10-16 move power supply over a little
    [ISS-Notify_Test-Harness.brd, ISS-Notify_Test-Harness.sch]
2014-09-06 Fixed L1 packages, changed USB header. Passes ERC, DRC, rats. Ship it.
    [ISS-Notify.brd, ISS-Notify.sch]
2014-09-09 Added fiducials per Screaming Circuits blog postw.
    [ISS-Notify.brd, ISS-Notify.sch]
2014-09-13 Add fiducials to board and library. Passes DRC, ERC, rats.
    [ISS-Notify.brd, ISS-Notify.sch]
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2014-09-13 Added LTC1153 package to library. Added to schematic without circuit. Needs another look in the morning.
    [ISS-Notify_Test-Harness.brd, ISS-Notify_Test-Harness.sch]
2014-09-14 Added fiducials, added note about LTC1153 fuse circuit.
    [ISS-Notify_Test-Harness.brd, ISS-Notify_Test-Harness.sch]
2014-09-17 Harness passes ERC, DRC, rats. Ready for review. D1 part number not finalized.
    [ISS-Notify_Test-Harness.brd, ISS-Notify_Test-Harness.sch]
2014-09-21 Changed resistor values for the LED according to datasheet
    [ISS-Notify.brd, ISS-Notify.sch]
2014-10-08 Ordered this board so it'd better be right.
    [ISS-Notify_Test-Harness.brd, ISS-Notify_Test-Harness.sch]

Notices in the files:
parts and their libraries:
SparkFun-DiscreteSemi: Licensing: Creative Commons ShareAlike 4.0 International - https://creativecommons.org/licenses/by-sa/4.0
